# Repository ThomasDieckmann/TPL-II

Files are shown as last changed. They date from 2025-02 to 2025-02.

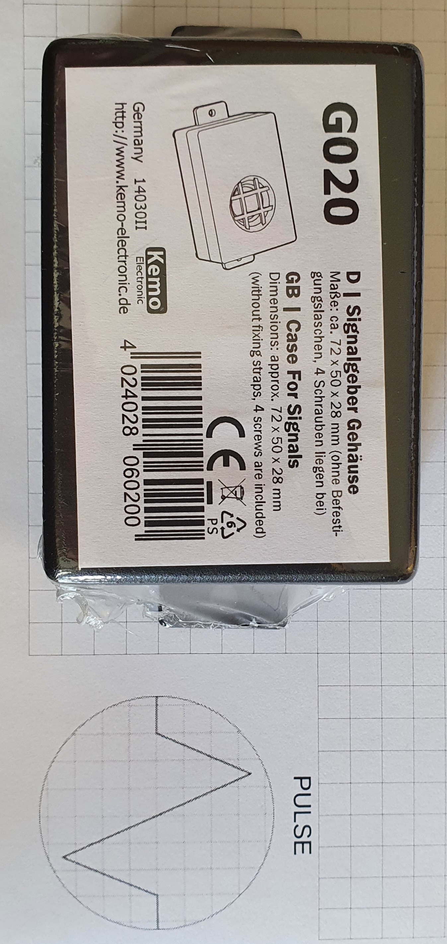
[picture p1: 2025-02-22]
photos/20220920_143856.jpg

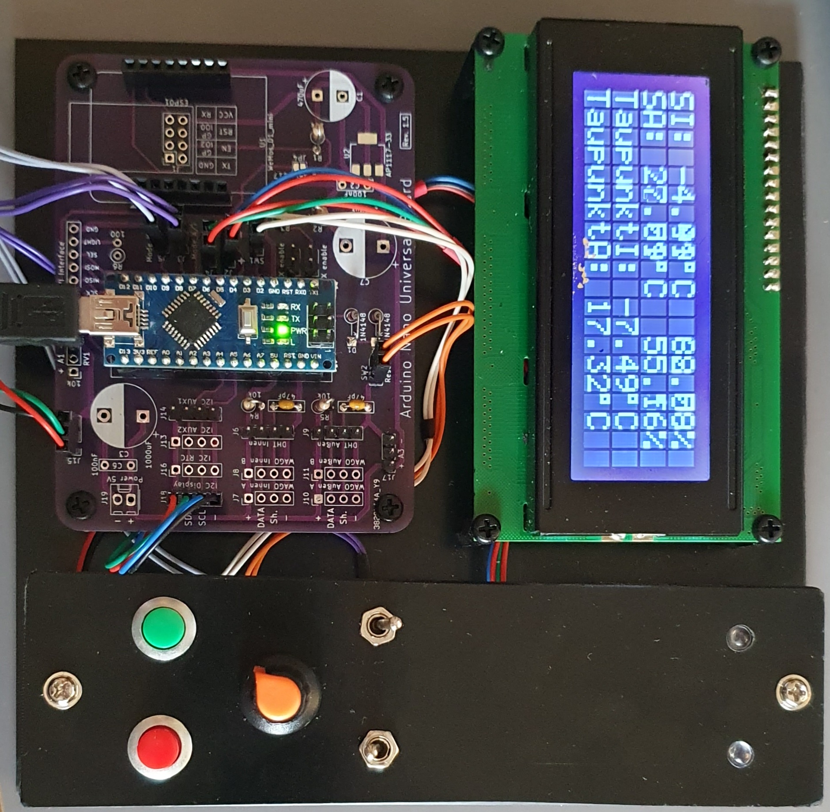
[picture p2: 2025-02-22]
photos/20221109_110422.jpg

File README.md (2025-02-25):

# TPL-II
## Taupunktlüftung II => dewpoint ventilation II
Description in progress....

The original project Taupunktlüftung is created by ct/Heise.

I extended and modified the code for some additional functions and some optional hardware has been added, too.

## purpose, just in case, you don't know...

## Hardware-Overview

the project hardware is based on some separate modules.
1. mainboard
2. power supply
3. relais board
4. I2C display

### the mainboard
the mainboard is developed by myself using KiCAD software. it has sockets for the Arduino nano, which is obligatory and for an ESP01 or Wemos D1. the source code published here is developed with Arduino IDE and has to be uploaded to the Atmega 328P chip with new bootloader. you can add an ESP8266 (wemos D1 mini pro or ESP01) to this system. this additional module is intendet to be programmed with Tasmota firmware. It reads serial data from the Arduino board an can deliver the data to an MQTT server. With serialsend you can use the ESP chip, so send serial data to the Arduino, for example, to initiate a button press.

### power supply

Switching power supply, board creaded with KiCAD. Output is 5V 10W (or more).

### relais board

2 relais baord from a chinese manufacturer. be sure to buy good quality with air gap between the contacts.

### I2C display

LCD background lit text display with 2 x 40 characters HD44780 compatible and I2C interface

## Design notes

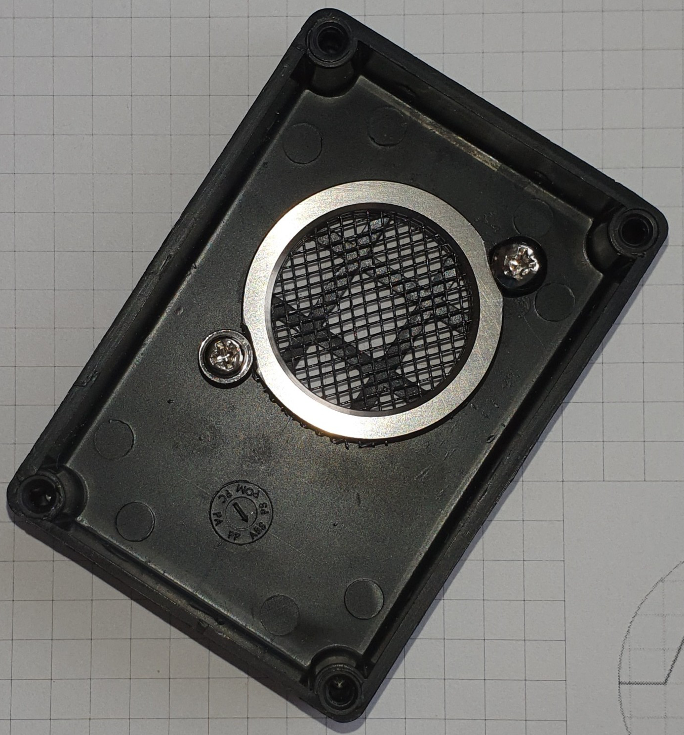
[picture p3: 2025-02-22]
photos/sensor_innen.jpg

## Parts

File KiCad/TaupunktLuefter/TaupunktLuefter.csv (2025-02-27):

Source: | /home/gerbil/KiCad_Projects/TaupunktLuefter/TaupunktLuefter.kicad_sch
Date: | Mi 25 Sep 2024 11:28:30 CEST
Tool: | Eeschema 6.0.11-2627ca5db0~126~ubuntu20.04.1
Generator: | /usr/share/kicad/plugins/bom_csv_grouped_by_value.py
Component Count: | 44
Individual Components:
Item | Qty | Reference(s) | Value | LibPart | Footprint | Datasheet
 |  | A1 | Arduino_Nano_v3.x | MCU_Module:Arduino_Nano_v3.x | Module:Arduino_Nano | http://www.mouser.com/pdfdocs/Gravitech_Arduino_Nano3_0.pdf
 |  | C1 | 470uF | Device:C_Polarized_Small | Capacitor_THT:CP_Radial_D10.0mm_P5.00mm | ~
 |  | C2 | 100nF | Device:C_Small | Capacitor_THT:C_Rect_L7.0mm_W2.0mm_P5.00mm | ~
 |  | C3 | 1000uF | Device:C_Polarized_Small | Capacitor_THT:CP_Radial_D12.5mm_P7.50mm | ~
 |  | C4 | 47pF | Device:C_Small | Capacitor_THT:C_Rect_L7.0mm_W2.0mm_P5.00mm | ~
 |  | C5 | 47pF | Device:C_Small | Capacitor_THT:C_Rect_L7.0mm_W2.0mm_P5.00mm | ~
 |  | C6 | 100nF | Device:C_Small | Capacitor_THT:C_Rect_L7.0mm_W2.0mm_P5.00mm | ~
 |  | C7 | 1000uF | Device:C_Polarized_Small | Capacitor_THT:CP_Radial_D12.5mm_P7.50mm | ~
 |  | D1 | 3V3 | Diode:BZV55B3V3 | Diode_THT:D_A-405_P2.54mm_Vertical_KathodeUp | https://assets.nexperia.com/documents/data-sheet/BZV55_SER.pdf
 |  | D2 | 1N4148 | Device:D_Small_Filled | Diode_THT:D_A-405_P2.54mm_Vertical_KathodeUp | ~
 |  | D3 | 1N4148 | Device:D_Small_Filled | Diode_THT:D_A-405_P2.54mm_Vertical_KathodeUp | ~
 |  | J1 | ESP01 | Connector_Generic:Conn_02x04_Odd_Even | Connector_PinSocket_2.54mm:PinSocket_2x04_P2.54mm_Vertical | ~
 |  | J2 | Rel1 | Connector:Conn_01x03_Male | Connector_PinHeader_2.54mm:PinHeader_1x03_P2.54mm_Vertical | ~
 |  | J3 | Mode_A/T | Connector:Conn_01x02_Male | Connector_PinHeader_2.54mm:PinHeader_1x02_P2.54mm_Vertical | ~
 |  | J4 | Rel2 | Connector:Conn_01x03_Male | Connector_PinHeader_2.54mm:PinHeader_1x03_P2.54mm_Vertical | ~
 |  | J5 | Mode_Kombi | Connector:Conn_01x02_Male | Connector_PinHeader_2.54mm:PinHeader_1x02_P2.54mm_Vertical | ~
 |  | J6 | DHT Innen | Connector:Conn_01x04_Male | Connector_PinHeader_2.54mm:PinHeader_1x04_P2.54mm_Vertical | ~
 |  | J7 | WAGO Innen A | Connector:Conn_01x04_Male | Connector_PinHeader_2.54mm:PinHeader_1x04_P2.54mm_Vertical | ~
 |  | J8 | WAGO Innen B | Connector:Conn_01x04_Male | Connector_PinHeader_2.54mm:PinHeader_1x04_P2.54mm_Vertical | ~
 |  | J9 | DHT Außen | Connector:Conn_01x04_Male | Connector_PinHeader_2.54mm:PinHeader_1x04_P2.54mm_Vertical | ~
 |  | J10 | WAGO Außen A | Connector:Conn_01x04_Male | Connector_PinHeader_2.54mm:PinHeader_1x04_P2.54mm_Vertical | ~
 |  | J11 | WAGO Außen B | Connector:Conn_01x04_Male | Connector_PinHeader_2.54mm:PinHeader_1x04_P2.54mm_Vertical | ~
 |  | J12 | 5V SPI Interface | Connector:Conn_01x08_Male | Connector_PinHeader_2.54mm:PinHeader_1x08_P2.54mm_Vertical | ~
 |  | J13 | I2C AUX2 | Connector:Conn_01x04_Male | Connector_PinHeader_2.54mm:PinHeader_1x04_P2.54mm_Vertical | ~
 |  | J14 | I2C AUX1 | Connector:Conn_01x04_Male | Connector_PinHeader_2.54mm:PinHeader_1x04_P2.54mm_Vertical | ~
 |  | J15 | A2 | Connector:Conn_01x03_Male | Connector_PinHeader_2.54mm:PinHeader_1x03_P2.54mm_Vertical | ~
 |  | J16 | I2C RTC | Connector:Conn_01x04_Male | Connector_PinHeader_2.54mm:PinHeader_1x04_P2.54mm_Vertical | ~
 |  | J17 | A3 | Connector:Conn_01x03_Male | Connector_PinHeader_2.54mm:PinHeader_1x03_P2.54mm_Vertical | ~
 |  | J18 | I2C Display | Connector:Conn_01x04_Male | Connector_PinHeader_2.54mm:PinHeader_1x04_P2.54mm_Vertical | ~
 |  | J19 | Power 5V | Connector:Conn_01x02_Male | Connector_Molex:Molex_KK-254_AE-6410-02A_1x02_P2.54mm_Vertical | ~
 |  | JP1 | RX enable | Jumper:Jumper_2_Bridged | Connector_PinHeader_2.54mm:PinHeader_1x02_P2.54mm_Vertical | ~
 |  | JP2 | TX enable | Jumper:Jumper_2_Bridged | Connector_PinHeader_2.54mm:PinHeader_1x02_P2.54mm_Vertical | ~
 |  | JP3 | 3V3 Sel Nano | Jumper:SolderJumper_2_Open | Jumper:SolderJumper-2_P1.3mm_Open_Pad1.0x1.5mm | ~
 |  | JP4 | 3V3 Sel 1117 | Jumper:SolderJumper_2_Open | Jumper:SolderJumper-2_P1.3mm_Open_Pad1.0x1.5mm | ~
 |  | R1 | 10k | Device:R | Resistor_THT:R_Axial_DIN0207_L6.3mm_D2.5mm_P2.54mm_Vertical | ~
 |  | R2 | 1k | Device:R | Resistor_THT:R_Axial_DIN0207_L6.3mm_D2.5mm_P2.54mm_Vertical | ~
 |  | R3 | 10k | Device:R | Resistor_THT:R_Axial_DIN0207_L6.3mm_D2.5mm_P2.54mm_Vertical | ~
 |  | R4 | 10k | Device:R | Resistor_THT:R_Axial_DIN0207_L6.3mm_D2.5mm_P2.54mm_Vertical | ~
 |  | R5 | 100 | Device:R | Resistor_THT:R_Axial_DIN0207_L6.3mm_D2.5mm_P2.54mm_Vertical | ~
 |  | RV1 | 10k | Device:R_Potentiometer | Connector_PinHeader_2.54mm:PinHeader_1x03_P2.54mm_Vertical | ~
 |  | SW1 | Timer | Switch:SW_Push | Connector_PinHeader_2.54mm:PinHeader_1x02_P2.54mm_Vertical | ~
 |  | SW2 | Reset | Switch:SW_Push | Connector_PinHeader_2.54mm:PinHeader_1x02_P2.54mm_Vertical | ~
 |  | U1 | WeMos_D1_mini | MCU_Module:WeMos_D1_mini | Module:WEMOS_D1_mini_light | https://wiki.wemos.cc/products:d1:d1_mini#documentation
 |  | U2 | AP1117-33 | Regulator_Linear:AP1117-33 | Package_TO_SOT_SMD:SOT-223-3_TabPin2 | http://www.diodes.com/datasheets/AP1117.pdf
Collated Components:
Item | Qty | Reference(s) | Value | LibPart | Footprint | Datasheet
1 | 1 | A1 | Arduino_Nano_v3.x | MCU_Module:Arduino_Nano_v3.x | Module:Arduino_Nano | http://www.mouser.com/pdfdocs/Gravitech_Arduino_Nano3_0.pdf
2 | 1 | C1 | 470uF | Device:C_Polarized_Small | Capacitor_THT:CP_Radial_D10.0mm_P5.00mm | ~
3 | 2 | C2, C6 | 100nF | Device:C_Small | Capacitor_THT:C_Rect_L7.0mm_W2.0mm_P5.00mm | ~
4 | 2 | C3, C7 | 1000uF | Device:C_Polarized_Small | Capacitor_THT:CP_Radial_D12.5mm_P7.50mm | ~
5 | 2 | C4, C5 | 47pF | Device:C_Small | Capacitor_THT:C_Rect_L7.0mm_W2.0mm_P5.00mm | ~
6 | 1 | D1 | 3V3 | Diode:BZV55B3V3 | Diode_THT:D_A-405_P2.54mm_Vertical_KathodeUp | https://assets.nexperia.com/documents/data-sheet/BZV55_SER.pdf
7 | 2 | D2, D3 | 1N4148 | Device:D_Small_Filled | Diode_THT:D_A-405_P2.54mm_Vertical_KathodeUp | ~
8 | 1 | J1 | ESP01 | Connector_Generic:Conn_02x04_Odd_Even | Connector_PinSocket_2.54mm:PinSocket_2x04_P2.54mm_Vertical | ~
9 | 1 | J2 | Rel1 | Connector:Conn_01x03_Male | Connector_PinHeader_2.54mm:PinHeader_1x03_P2.54mm_Vertical | ~
10 | 1 | J3 | Mode_A/T | Connector:Conn_01x02_Male | Connector_PinHeader_2.54mm:PinHeader_1x02_P2.54mm_Vertical | ~
11 | 1 | J4 | Rel2 | Connector:Conn_01x03_Male | Connector_PinHeader_2.54mm:PinHeader_1x03_P2.54mm_Vertical | ~
12 | 1 | J5 | Mode_Kombi | Connector:Conn_01x02_Male | Connector_PinHeader_2.54mm:PinHeader_1x02_P2.54mm_Vertical | ~
13 | 1 | J6 | DHT Innen | Connector:Conn_01x04_Male | Connector_PinHeader_2.54mm:PinHeader_1x04_P2.54mm_Vertical | ~
14 | 1 | J7 | WAGO Innen A | Connector:Conn_01x04_Male | Connector_PinHeader_2.54mm:PinHeader_1x04_P2.54mm_Vertical | ~
15 | 1 | J8 | WAGO Innen B | Connector:Conn_01x04_Male | Connector_PinHeader_2.54mm:PinHeader_1x04_P2.54mm_Vertical | ~
16 | 1 | J9 | DHT Außen | Connector:Conn_01x04_Male | Connector_PinHeader_2.54mm:PinHeader_1x04_P2.54mm_Vertical | ~
17 | 1 | J10 | WAGO Außen A | Connector:Conn_01x04_Male | Connector_PinHeader_2.54mm:PinHeader_1x04_P2.54mm_Vertical | ~
18 | 1 | J11 | WAGO Außen B | Connector:Conn_01x04_Male | Connector_PinHeader_2.54mm:PinHeader_1x04_P2.54mm_Vertical | ~
19 | 1 | J12 | 5V SPI Interface | Connector:Conn_01x08_Male | Connector_PinHeader_2.54mm:PinHeader_1x08_P2.54mm_Vertical | ~
20 | 1 | J13 | I2C AUX2 | Connector:Conn_01x04_Male | Connector_PinHeader_2.54mm:PinHeader_1x04_P2.54mm_Vertical | ~
21 | 1 | J14 | I2C AUX1 | Connector:Conn_01x04_Male | Connector_PinHeader_2.54mm:PinHeader_1x04_P2.54mm_Vertical | ~
22 | 1 | J15 | A2 | Connector:Conn_01x03_Male | Connector_PinHeader_2.54mm:PinHeader_1x03_P2.54mm_Vertical | ~
23 | 1 | J16 | I2C RTC | Connector:Conn_01x04_Male | Connector_PinHeader_2.54mm:PinHeader_1x04_P2.54mm_Vertical | ~
24 | 1 | J17 | A3 | Connector:Conn_01x03_Male | Connector_PinHeader_2.54mm:PinHeader_1x03_P2.54mm_Vertical | ~
25 | 1 | J18 | I2C Display | Connector:Conn_01x04_Male | Connector_PinHeader_2.54mm:PinHeader_1x04_P2.54mm_Vertical | ~
26 | 1 | J19 | Power 5V | Connector:Conn_01x02_Male | Connector_Molex:Molex_KK-254_AE-6410-02A_1x02_P2.54mm_Vertical | ~
27 | 1 | JP1 | RX enable | Jumper:Jumper_2_Bridged | Connector_PinHeader_2.54mm:PinHeader_1x02_P2.54mm_Vertical | ~
28 | 1 | JP2 | TX enable | Jumper:Jumper_2_Bridged | Connector_PinHeader_2.54mm:PinHeader_1x02_P2.54mm_Vertical | ~
29 | 1 | JP3 | 3V3 Sel Nano | Jumper:SolderJumper_2_Open | Jumper:SolderJumper-2_P1.3mm_Open_Pad1.0x1.5mm | ~
30 | 1 | JP4 | 3V3 Sel 1117 | Jumper:SolderJumper_2_Open | Jumper:SolderJumper-2_P1.3mm_Open_Pad1.0x1.5mm | ~
31 | 3 | R1, R3, R4 | 10k | Device:R | Resistor_THT:R_Axial_DIN0207_L6.3mm_D2.5mm_P2.54mm_Vertical | ~
32 | 1 | R2 | 1k | Device:R | Resistor_THT:R_Axial_DIN0207_L6.3mm_D2.5mm_P2.54mm_Vertical | ~
33 | 1 | R5 | 100 | Device:R | Resistor_THT:R_Axial_DIN0207_L6.3mm_D2.5mm_P2.54mm_Vertical | ~
34 | 1 | RV1 | 10k | Device:R_Potentiometer | Connector_PinHeader_2.54mm:PinHeader_1x03_P2.54mm_Vertical | ~
35 | 1 | SW1 | Timer | Switch:SW_Push | Connector_PinHeader_2.54mm:PinHeader_1x02_P2.54mm_Vertical | ~
36 | 1 | SW2 | Reset | Switch:SW_Push | Connector_PinHeader_2.54mm:PinHeader_1x02_P2.54mm_Vertical | ~
37 | 1 | U1 | WeMos_D1_mini | MCU_Module:WeMos_D1_mini | Module:WEMOS_D1_mini_light | https://wiki.wemos.cc/products:d1:d1_mini#documentation
38 | 1 | U2 | AP1117-33 | Regulator_Linear:AP1117-33 | Package_TO_SOT_SMD:SOT-223-3_TabPin2 | http://www.diodes.com/datasheets/AP1117.pdf

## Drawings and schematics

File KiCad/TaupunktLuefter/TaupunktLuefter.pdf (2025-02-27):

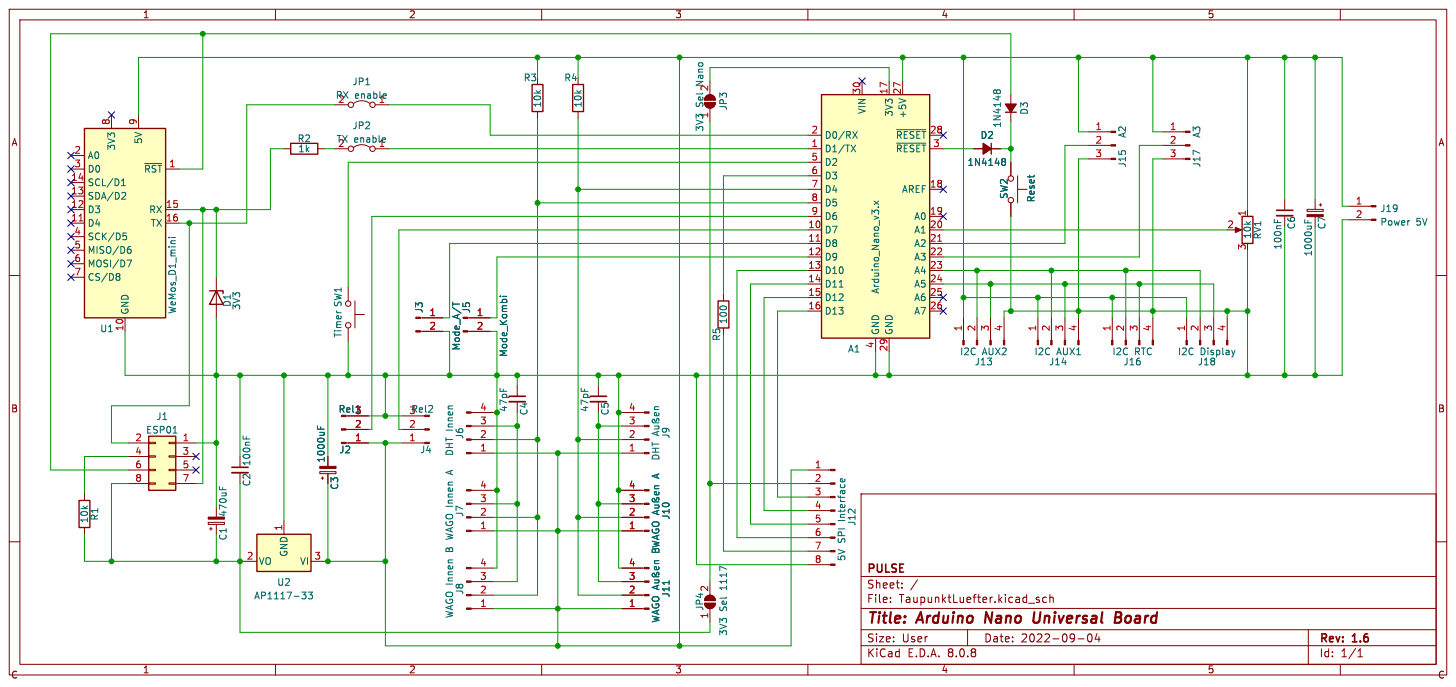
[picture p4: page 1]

Sheet: /
File: TaupunktLuefter.kicad_sch
Title: Arduino Nano Universal Board

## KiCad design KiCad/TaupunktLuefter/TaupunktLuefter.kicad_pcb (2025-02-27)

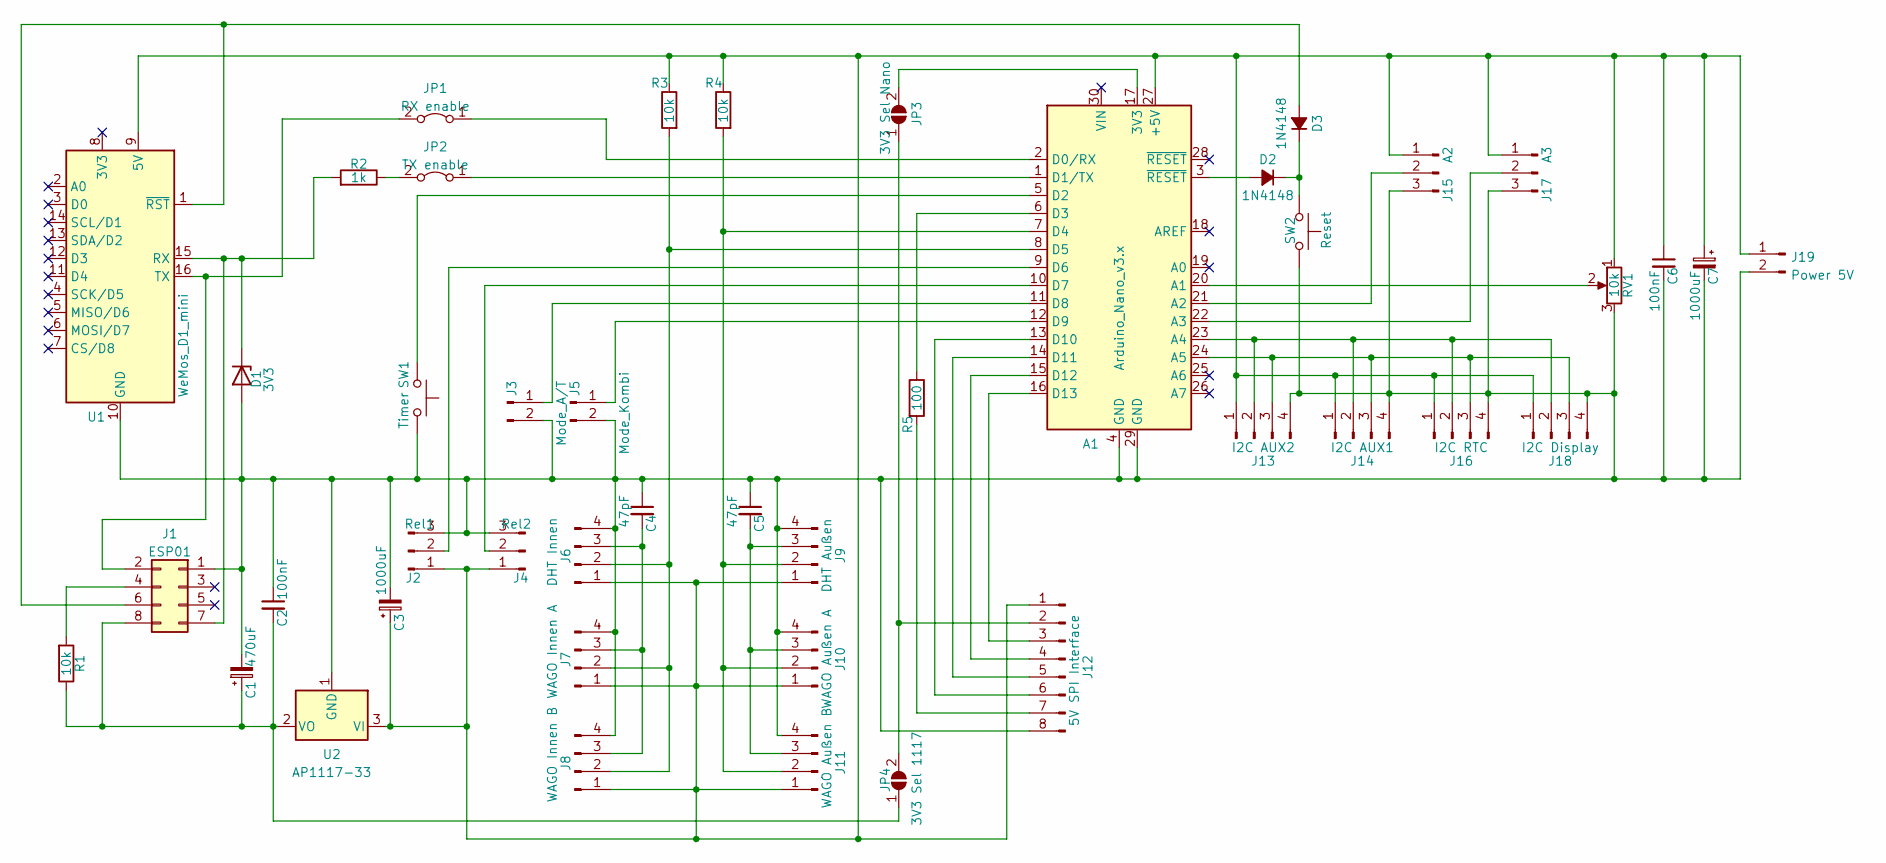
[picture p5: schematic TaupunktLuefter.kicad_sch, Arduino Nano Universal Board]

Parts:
A1: Arduino_Nano_v3.x; Arduino_Nano
C1: 470uF; CP_Radial_D10.0mm_P5.00mm
C2, C6: 100nF; C_Rect_L7.0mm_W2.0mm_P5.00mm
C3, C7: 1000uF; CP_Radial_D12.5mm_P7.50mm
C4, C5: 47pF; C_Rect_L7.0mm_W2.0mm_P5.00mm
D1: 3V3; D_A-405_P2.54mm_Vertical_KathodeUp
D2, D3: 1N4148; D_A-405_P2.54mm_Vertical_KathodeUp
J1: ESP01; PinSocket_2x04_P2.54mm_Vertical
J2: Rel1; PinHeader_1x03_P2.54mm_Vertical
J3: Mode_A/T; PinHeader_1x02_P2.54mm_Vertical
J4: Rel2; PinHeader_1x03_P2.54mm_Vertical
J5: Mode_Kombi; PinHeader_1x02_P2.54mm_Vertical
J6: DHT Innen; PinHeader_1x04_P2.54mm_Vertical
J7: WAGO Innen A; PinHeader_1x04_P2.54mm_Vertical
J8: WAGO Innen B; PinHeader_1x04_P2.54mm_Vertical
J9: DHT Außen; PinHeader_1x04_P2.54mm_Vertical
J10: WAGO Außen A; PinHeader_1x04_P2.54mm_Vertical
J11: WAGO Außen B; PinHeader_1x04_P2.54mm_Vertical
J12: 5V SPI Interface; PinHeader_1x08_P2.54mm_Vertical
J13: I2C AUX2; PinHeader_1x04_P2.54mm_Vertical
J14: I2C AUX1; PinHeader_1x04_P2.54mm_Vertical
J15: A2; PinHeader_1x03_P2.54mm_Vertical
J16: I2C RTC; PinHeader_1x04_P2.54mm_Vertical
J17: A3; PinHeader_1x03_P2.54mm_Vertical
J18: I2C Display; PinHeader_1x04_P2.54mm_Vertical
J19: Power 5V; Molex_KK-254_AE-6410-02A_1x02_P2.54mm_Vertical
JP1: RX enable; PinHeader_1x02_P2.54mm_Vertical
JP2: TX enable; PinHeader_1x02_P2.54mm_Vertical
JP3: 3V3 Sel Nano; SolderJumper-2_P1.3mm_Open_Pad1.0x1.5mm
JP4: 3V3 Sel 1117; SolderJumper-2_P1.3mm_Open_Pad1.0x1.5mm
R1, R3, R4: 10k; R_Axial_DIN0207_L6.3mm_D2.5mm_P2.54mm_Vertical
R2: 1k; R_Axial_DIN0207_L6.3mm_D2.5mm_P2.54mm_Vertical
R5: 100; R_Axial_DIN0207_L6.3mm_D2.5mm_P2.54mm_Vertical
RV1: 10k; PinHeader_1x03_P2.54mm_Vertical
SW1: Timer; PinHeader_1x02_P2.54mm_Vertical
SW2: Reset; PinHeader_1x02_P2.54mm_Vertical
U1: WeMos_D1_mini; WEMOS_D1_mini_light
U2: AP1117-33; SOT-223-3_TabPin2

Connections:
unnamed: A1.1 (D1/TX), JP2.1 (A)
unnamed: A1.2 (D0/RX), JP1.1 (A)
unnamed: A1.3 (~RESET), D2.2 (A)
unnamed: A1.5 (D2), SW1.1
unnamed: A1.6 (D3), R5.1
unnamed: A1.7 (D4), J9.2, J10.2, J11.2, R4.2
unnamed: A1.8 (D5), J6.2, J7.2, J8.2, R3.2
unnamed: A1.9 (D6), J2.2
unnamed: A1.10 (D7), J4.2
unnamed: A1.11 (D8), J3.1
unnamed: A1.12 (D9), J5.1
unnamed: A1.13 (D10), J12.6
unnamed: A1.14 (D11), J12.5
unnamed: A1.15 (D12), J12.4
unnamed: A1.16 (D13), J12.3
unnamed: A1.17 (3V3), JP3.2 (B)
unnamed: A1.20 (A1), RV1.2
unnamed: A1.21 (A2), J15.2
unnamed: A1.22 (A3), J17.2
unnamed: A1.23 (A4), J13.2, J14.2, J16.2, J18.2
unnamed: A1.24 (A5), J13.3, J14.3, J16.3, J18.3
unnamed: A1.27 (+5V), C3.1, C6.1, C7.1, J2.1, J4.1, J6.1, J7.1, J8.1, J9.1, J10.1, J11.1, J12.1, J13.1, J14.1, J15.1, J16.1, J17.1, J18.1, J19.1, R3.1, R4.1, RV1.1, U1.9 (5V), U2.3 (VI)
unnamed: A1.4 (GND), A1.29 (GND), C1.2, C2.1, C3.2, C4.1, C5.1, C6.2, C7.2, D1.2 (A), J1.1, J2.3, J3.2, J4.3, J5.2, J6.4, J7.4, J8.4, J9.4, J10.4, J11.4, J12.8, J13.4, J14.4, J15.3, J16.4, J17.3, J18.4, J19.2, RV1.3, SW1.2, SW2.2, U1.10 (GND), U2.1 (GND)
unnamed: C1.1, C2.2, J1.8, JP4.1 (A), R1.1, U2.2 (VO)
unnamed: C4.2, J6.3, J7.3, J8.3
unnamed: C5.2, J9.3, J10.3, J11.3
unnamed: D2.1 (K), D3.1 (K), SW2.1
unnamed: D3.2 (A), J1.6, U1.1 (~RST)
unnamed: J1.2, JP1.2 (B), U1.16 (TX)
unnamed: J1.4, R1.2
unnamed: D1.1 (K), J1.7, R2.2, U1.15 (RX)
unnamed: J12.2, JP3.1 (A), JP4.2 (B)
unnamed: J12.7, R5.2
unnamed: JP2.2 (B), R2.1

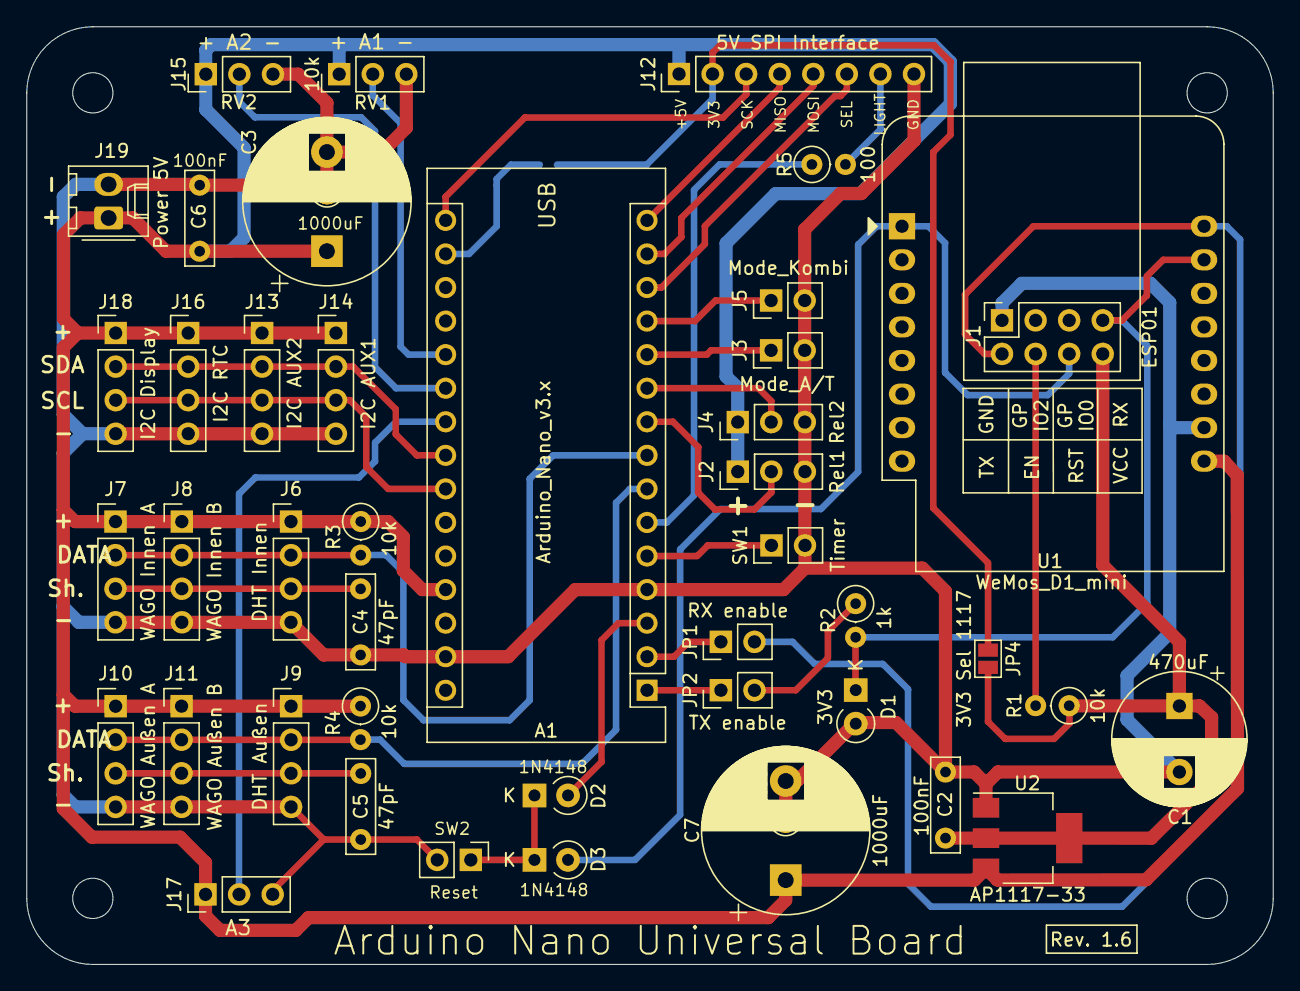
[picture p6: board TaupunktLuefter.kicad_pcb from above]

Board: 2 copper layers, 94.3 x 71.0 mm, 44 parts (1 on the bottom side), 34 nets.

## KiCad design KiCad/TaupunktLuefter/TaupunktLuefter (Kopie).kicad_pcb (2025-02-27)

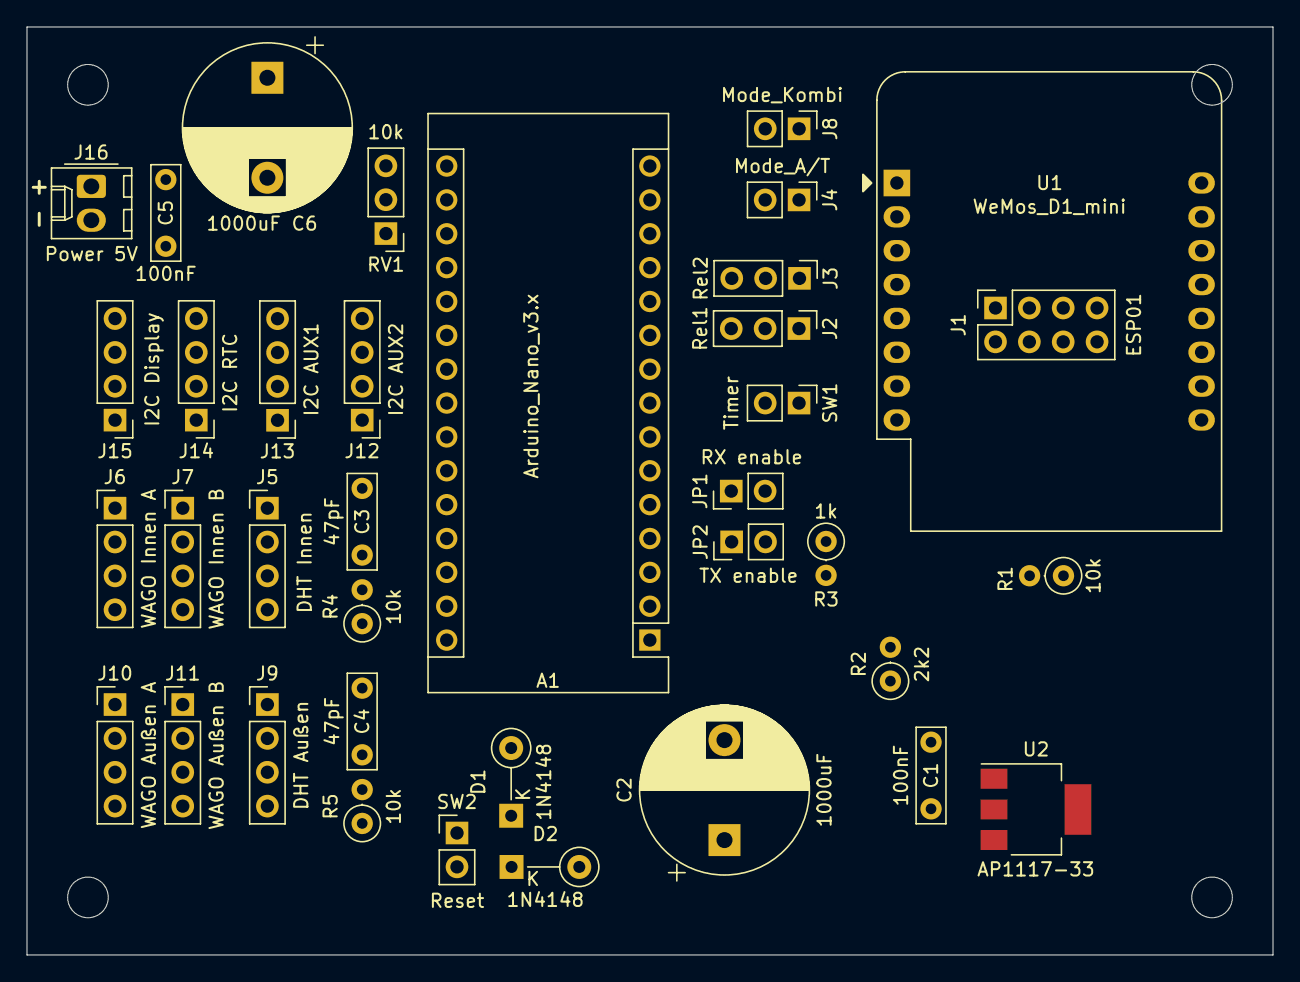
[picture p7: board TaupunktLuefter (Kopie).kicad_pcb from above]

Board: 2 copper layers, 93.5 x 69.6 mm, 37 parts (0 on the bottom side), 25 nets, no tracks yet.

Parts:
A1: Arduino_Nano_v3.x; Arduino_Nano
C1, C5: 100nF; C_Rect_L7.0mm_W2.0mm_P5.00mm
C2, C6: 1000uF; CP_Radial_D12.5mm_P7.50mm
C3, C4: 47pF; C_Rect_L7.0mm_W2.0mm_P5.00mm
D1, D2: 1N4148; D_A-405_P5.08mm_Vertical_KathodeUp
J1: ESP01; PinSocket_2x04_P2.54mm_Vertical
J2: Rel1; PinHeader_1x03_P2.54mm_Vertical
J3: Rel2; PinHeader_1x03_P2.54mm_Vertical
J4: Mode_A/T; PinHeader_1x02_P2.54mm_Vertical
J5: DHT Innen; PinHeader_1x04_P2.54mm_Vertical
J6: WAGO Innen A; PinHeader_1x04_P2.54mm_Vertical
J7: WAGO Innen B; PinHeader_1x04_P2.54mm_Vertical
J8: Mode_Kombi; PinHeader_1x02_P2.54mm_Vertical
J9: DHT Außen; PinHeader_1x04_P2.54mm_Vertical
J10: WAGO Außen A; PinHeader_1x04_P2.54mm_Vertical
J11: WAGO Außen B; PinHeader_1x04_P2.54mm_Vertical
J12: I2C AUX2; PinHeader_1x04_P2.54mm_Vertical
J13: I2C AUX1; PinHeader_1x04_P2.54mm_Vertical
J14: I2C RTC; PinHeader_1x04_P2.54mm_Vertical
J15: I2C Display; PinHeader_1x04_P2.54mm_Vertical
J16: Power 5V; Molex_KK-254_AE-6410-02A_1x02_P2.54mm_Vertical
JP1: RX enable; PinHeader_1x02_P2.54mm_Vertical
JP2: TX enable; PinHeader_1x02_P2.54mm_Vertical
R1, R4, R5: 10k; R_Axial_DIN0207_L6.3mm_D2.5mm_P2.54mm_Vertical
R2: 2k2; R_Axial_DIN0207_L6.3mm_D2.5mm_P2.54mm_Vertical
R3: 1k; R_Axial_DIN0207_L6.3mm_D2.5mm_P2.54mm_Vertical
RV1: 10k; PinHeader_1x03_P2.54mm_Vertical
SW1: Timer; PinHeader_1x02_P2.54mm_Vertical
SW2: Reset; PinHeader_1x02_P2.54mm_Vertical
U1: WeMos_D1_mini; WEMOS_D1_mini_light
U2: AP1117-33; SOT-223-3_TabPin2

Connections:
unnamed: A1.1 (D1/TX), JP2.1 (A)
unnamed: A1.2 (D0/RX), JP1.1 (A)
unnamed: A1.5 (D2), SW1.2
unnamed: A1.7 (D4), J9.3, J10.3, J11.3, R5.2
unnamed: A1.8 (D5), J5.3, J6.3, J7.3, R4.2
unnamed: A1.9 (D6), J2.2
unnamed: A1.10 (D7), J3.2
unnamed: A1.11 (D8), J4.2
unnamed: A1.20 (A1), RV1.2
unnamed: A1.23 (A4), J12.3, J13.3, J14.3, J15.3
unnamed: A1.24 (A5), J12.2, J13.2, J14.2, J15.2
unnamed: A1.27 (+5V), C5.1, C6.1, J5.4, J6.4, J7.4, J9.4, J10.4, J11.4, J12.4, J13.4, J14.4, J15.4, J16.1, R4.1, R5.1, RV1.1, U1.9 (5V)
unnamed: A1.28 (~RESET), D1.2 (A)
unnamed: C1.2, J1.8, R1.1, U2.2 (VO)
unnamed: C2.1, J2.3, J3.3, U2.3 (VI)
unnamed: C3.2, J5.2, J6.2, J7.2
unnamed: C4.2, J9.2, J10.2, J11.2
unnamed: D1.1 (K), D2.1 (K), SW2.2
unnamed: D2.2 (A), J1.6, U1.1 (~RST)
unnamed: A1.4 (GND), A1.29 (GND), C1.1, C2.2, C3.1, C4.1, C5.2, C6.2, J1.1, J2.1, J3.1, J4.1, J5.1, J6.1, J7.1, J8.1, J9.1, J10.1, J11.1, J12.1, J13.1, J14.1, J15.1, J16.2, R2.1, RV1.3, SW1.1, SW2.1, U1.10 (GND), U2.1 (GND)
unnamed: J1.2, JP1.2 (B), U1.16 (TX)
unnamed: J1.4, R1.2
unnamed: A1.12 (D9), J8.2
unnamed: JP2.2 (B), R3.1
unnamed: J1.7, R2.2, R3.2, U1.15 (RX)

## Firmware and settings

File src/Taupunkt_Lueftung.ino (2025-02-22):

/* 

Original bei Heise
Upgrade by Thomas Dieckmann ;-)


Entwicklungs-Plattform: Arduino IDE 1.8.19 / Linux

Pinbelegung Arduino Nano:
=========================

D0   RX                   D11  opt. MOSI
D1   TX                   D12  opt. MISO
D2   Timer_Knopf          D13  opt. SCK/LED f. Serial ACK
D3                        A0   Randomizer (frei)
D4   DHT außen            A1   
D5   DHT innen            A2   Poti
D6   Relais1              A3
D7   Relais2              A4   I2C SDA
D8   MODE: Timer/Auto     A5   I2C SCL
D9   MODE: Timer&Sensor   A6
D10  opt. CS              A7



HELP: https://jsonformatter.org/#

"Innen":{"Temperature":7.86,"Humidity":40.86,"DewPoint":-4.60},"Aussen":{"Temperature":15.86,"Humidity":45.86,"DewPoint":4.23},"Timer":{"Preset":300,"Remain":0},"Actuators":{"Relay1":"OFF","Relay2":"OFF"},"Mode":"Combi2","TempUnit":"C","TimeUnit":"seconds","Version":"1.5.7"}

==>
=== test:     
*/

#define PRG_VERSION               "2.0.5"
#define EEPROM_ID_WERT            1     // sozusagen eine Sub-Version um zu prüfen, ob Settings aus dem EEPROM gelesen werden sollen
#define EEPROM_BANK               0     // Speicher-Seite, damit die Daten woanders liegen können um den EEPORM-Speicher zu schonen
#define EEPROM_BANKGROESSE        16    // definiert die Größe der Speicherbank (derzeit 16)

// l10n stuff
#define DE 1
#define EN 2
#define LANGUAGE DE

/* Commands:
 *  B   press button
 *  0   timer = zero
 *  J   send JSON
 *  P   ping
 *  RR  reset 328P chip
 */
/*
   TODO/Changelog
   ==============

   Todo:
   - optimizing Display outputs (obvious after starting, with lange page refresh interval)
   - password-option, block setup (Pfeil zurück Seite 2 Zeile 1 Symbol 15)
   - Bugs: A/H command don't work properly

   
   V2.0.5 v. 17.01.2024:
   ---------------------
   - remove password routine, i'll decide later, if it'll be needed, when it's ready...

   V2.0.4 v. 17.01.2024:
   ---------------------
   - Bugs: Offset/settings for inner temp / outer temp

   V2.0.3 v. 17.01.2024:
   ---------------------
   - some changes for Config/commands

   V2.0.2 v. 16.01.2024:
   ---------------------
   - accept commands and use switch-structure... BOJPR
   
   V2.0.1 v. 16.01.2024:
   ---------------------
   - accept O via Serial as reset Timer to zero
   - accept R via Serial as Reset, has to be repeated

   V2.0.0 v. 16.01.2024:
   ---------------------
   - accept B via Serial as BUTTON
   
   V1.5.8 v. 13.01.2024:
   ---------------------
   - interprete any serial input from 8266 as Trigger

   V1.5.7 v. 12.01.2024:
   ---------------------
   - simplified JSON output

   V1.5.6 v. 03.10.2023:
   ---------------------
   - bug: temperature calibration

   V1.5.5 v. 01.10.2023:
   ---------------------
   - möglicher Fehler bei Temperatur-Kalibrierung => zunächst bei Dummy-Sensor-Werten
     Fix-Temperatur und dann Suche nach Codestellen, wo es haken könnte
     => vermutlich durch Groß/Kleinschreibung gelöst
   
   V1.5.4 v. 25.11.2022:
   ---------------------
   - l10n: DE & EN for german and english

   V1.5.3 v. 24.11.2022:
   ---------------------
   - EEPROM-BANK Größe verwenden, damit später vergrößert und das Passwort
     abgespeichert werden kann

   V1.5.2 v. 23.11.2022:
   ---------------------
   - Zusammenfassung von Textausgaben mit Sonderzeichen (oktal) spart Speicherplatz
   - Funktion für Grad-Celsius-Anzeige besser genutzt, spart auch Speicher
   - Ersatz ß gegen ss in Übergabestring für Tasmota Serial2MQTT-Bridge,
     JSON wird nun sauber erkannt
   - einfache serielle Debugging Ausgaben nur noch, wenn kein JSON ausgegeben wird
   - Vorbereitung größere EEPROM-BANK für Passwort etc.

   V1.5.1 v. 16.11.2022:
   ---------------------
   - Auslagerung ja/nein-Funktion, die wird häufiger benötigt

   V1.5.0 v. 11.11.2022:
   ---------------------
   - Einbau Speicherroutine unter Verwendung verschiedener Speicherblöcke um EEPROM zu schonen

   V1.4.9 v. 11.11.2022:
   ---------------------
   - Ausgabe sämtlicher Einstellungsmöglichkeiten => Menue
   - Speichern erst einmal deaktiviert, Speicherroutine muss noch codiert werden

   V1.4.8 v. 10.11.2022:
   ---------------------
   - Setup-Routine für Hysterese, Differenz, Sensor-Korrektur-Werte
     derzeit realisiert: Schalt-Differenz und Hysterese
                         Speichern im EEPROM

   V1.4.7 v. 09.11.2022:
   ---------------------
   - Bugfix: Feuchte-Update bei jedem Durchlauf auf Seite 1, alt-Wert wurde nicht gesetzt

   V1.4.6 v. 09.11.2022:
   ---------------------
   - Ausgabe Sensoren-Check von 1+2 auf Innen/Außen geändert
   - 4. Betriebsart = Kombi-2, Also erst Timer, dann Auto
   - Bei Änderung der Betriebsart wird Seite2 angezeigt
   - Bugfix: nach Wechsel auf Seite 1 wird bsp. 1° bzw. 1% zu viel angezeigt
     (Vorsicht bei ++ Verwendung! a = b++; ist nicht immer gewollt!)
   
   V1.4.5 v. 27.08.2022:
   ---------------------
   - Korrektur der Sekundenanzeige (cast: long bei JSON-String)   ok, beide Teile des Produktes gecastet... dann passt's.
   
   V1.4.4 v. 26.08.2022:
   ---------------------
   - optionale serielle Ausgabe als JSON-String per #define       ok, per define JSON_OUTPUT

   V1.4.3 v. 26.08.2022:
   ---------------------
   - Dummy-Sensoren einzeln per #DEFINE
   
   V1.4.2 v. 25.08.2022:
   ---------------------
   - Komplizierten Wechsel-Murks der Animation wegmachen           ok, umgestellt auf Zähler und index
   - Eigenen Timer dafür einbauen, wie beim Seitenwechsel          ok
   - Zugriff per char(symbol_zaehler) (0 bis MAXSYMBOLS)           ok, siehe oben
     dann braucht es rest_laufzeit_fuenftel oder wasauchimmer
     nicht mehr.
   - elegantere Lösung mit den #ifdefs finden vielleicht kann      ok, #if a == b...
     das nach dem #ifdef mit einfachen ifs machen?
   - ein paar Animationen hinzufügen                               ok
*/

// Dieser Code benötigt zwingend die folgenden Libraries:
#include "DHT.h"
#include <Wire.h> 
#include <LiquidCrystal_I2C.h>
#include <avr/wdt.h>
#include <EEPROM.h>


#if LANGUAGE == DE
   #include "l10n/constants_de.h"
#elif LANGUAGE == EN
   #include "l10n/constants_en.h"
#endif




// #define DISPLAYTEST                          // Testen des LCD Character-Set
// #define DEBUG                                // eventuell bleibt etwas Test-Code übrig
#define WRITE_EEPROM                            // Aktiviere EEPROM Schreib-Routine
//#define DUMMYSENSOR_I                           // wenn man keine Sensoren hat, hilft der Zufall
//#define DUMMYSENSOR_A                           // wenn man keine Sensoren hat, hilft der Zufall
#define SYMBOLSET                  3            // verschiedene Symbolsets möglich (für Animation)
// ***************  Arduino-Pin-Definitionen (siehe oben)  **************
#define TIMER_KNOPF_PIN            2            // Eingang (interner) Pull-Up für Auslösung Timer
#define DHTPIN_AUSSEN              4            // Datenleitung für den DHT-Sensor 2 (außen)
#define DHTPIN_INNEN               5            // Datenleitung für den DHT-Sensor 1 (innen)
#define RELAIS1_PIN                6            // Anschluss des Lüfter-Relais #1
#define RELAIS2_PIN                7            // Anschluss des Lüfter-Relais #2
#define TIMER_AUTO_PIN             8            // Schalter Timer/Auto
#define KOMBI_PIN                  9            // Timer und Sensor kombiniert (interner Pullup)
#define POTI_PIN                   A2           // Pin für das Timer-Poti die 10bit werden umgerechnet auf 1-25
#define ACK_PIN                    13           // Quittierungs-Pin
//  *****************  für bessere Wartbarkeit des Codes  ***************
#define FORCE                      true         // erzwingen der Ausgabe wg. Wechsel der Seite
#define RELAIS_EIN                 LOW          // Das Relais wird geschaltet, wenn der Eingang auf TTL LOW liegt
#define RELAIS_AUS                 HIGH
#define MODE_TIMER                 LOW          // wenn LOW, dann ist der Lüfter aus oder vom Timer gesteuert
#define MODE_KOMBI                 LOW          // wenn LOW, dann kombiniere Timer & Sensor-Betrieb
#define DHTTYPE_INNEN              DHT22        // DHT 22 innen
#define DHTTYPE_AUSSEN             DHT22        // DHT 22 außen
#define SENSOR_INTERVALL           3            // in Sekunden, Pausen zwischen den Auslesezyklen für die Sensoren
#define SEITEN_INTERVALL           7            // in Sekunden, Wartezeit auf Seitenwechsel
// *************  Korrekturwerte der einzelnen Sensorwerte  *************
#define KORREKTUR_TEMP_INNEN      -1            // Korrekturwert Innensensor Temperatur
#define KORREKTUR_TEMP_AUSSEN     -1            // Korrekturwert Außensensor Temperatur
#define KORREKTUR_FEUCHTE_INNEN    0            // Korrekturwert Innensensor Luftfeuchtigkeit
#define KORREKTUR_FEUCHTE_AUSSEN   0            // Korrekturwert Außensensor Luftfeuchtigkeit
// *******************  weitere wichtige Konstanten  ********************
#define SCHALT_MIN                 2.5          // minimaler Taupunktunterschied, bei dem das Relais schaltet
#define HYSTERESE                  1.0          // Abstand von Ein- und Ausschaltpunkt
#define TEMP_INNEN_MIN            10.0          // Minimale Innentemperatur, bei der die Lüftung aktiviert wird
#define TEMP_AUSSEN_MIN          -10.0          // Minimale Außentemperatur, bei der die Lüftung aktiviert wird
#define MAX_MILLIS                 4294967295   // millis() liefert den Datentyp unsigned long, also 32 bit
#define MAX_EINSTELLWERTE          9            // Anzahl der Werte, die angesehen und verändert werden können
// **************************  Betriebsarten  ****************************
#define BETRIEBSART_AUTO           0
#define BETRIEBSART_TIMER          1
#define BETRIEBSART_KOMBI_1        2
#define BETRIEBSART_KOMBI_2        3
// ******************  Optionen für Eingaberoutine  **********************                    
#define OPTION_GRAD                0
#define OPTION_FEUCHTE             1
#define OPTION_SEKUNDEN            2
#define MAX_PASSWORT_LAENGE        6
// ******************  alles nur für den JSON OUTPUT  ********************
#define JSON_OUTPUT                             // muss nur definiert sein. Sendet die Daten als JSON-String


// allgemeine Daten
float Feuchte_innen                =  0,           // Innen-Luftfeuchtigkeit, voerher H1
      Temperatur_innen             =  0,           // Innen-Tmperatur, vorher T1
      Feuchte_aussen               =  0,           // Außen-Luftfeuchtigkeit, vorher H2
      Temperatur_aussen            =  0,           // Außen-Temperatur, vorher T2
      Taupunkt_innen               =  0,           // Innen-Taupunkt
      Taupunkt_aussen              =  0,           // Außen-Taupunkt
      Feuchte_innen_alt            =  0,           // Innen-Luftfeuchtigkeit ALT
      Temperatur_innen_alt         =  0,           // Innen-Temperatur ALT
      Feuchte_aussen_alt           =  0,           // Außen-Luftfeuchtigkeit ALT
      Temperatur_aussen_alt        =  0,           // Außen-Temperatur ALT
      Taupunkt_innen_alt           =  0,           // Innen-Taupunkt ALT
      Taupunkt_aussen_alt          =  0,           // Außen-Taupunkt ALT
      DeltaTP                      =  0,           // Differenz der Taupunkte
      DeltaTP_alt                  =  0;           // Differenz der Taupunkte ALT

// beeinflusst das Schaltverhalten und Intervalle
float schalt_min                   =  SCHALT_MIN,  // minimale Differenz der Taupunkte für Aktivieren der Lüftung
      hysterese                    =  HYSTERESE,
      korrektur_temp_innen         =  KORREKTUR_TEMP_INNEN,
      korrektur_temp_aussen        =  KORREKTUR_TEMP_AUSSEN,
      korrektur_Feuchte_innen      =  KORREKTUR_FEUCHTE_INNEN,
      korrektur_Feuchte_aussen     =  KORREKTUR_FEUCHTE_AUSSEN,
      temp_innen_min               =  TEMP_INNEN_MIN,
      temp_aussen_min              =  TEMP_AUSSEN_MIN;
      
byte  sensor_intervall_byte        =  SENSOR_INTERVALL,
      seiten_intervall_byte        =  SEITEN_INTERVALL;
     
/*    // Vorbereitung um in einer der nächsten Versionen das Flackern bei der Setup-Anzeige zu deaktivieren
      schalt_min_alt               =  -666.0,
      hysterese_alt                =  -666.0,
      korrektur_temp_innen_alt     =  -666.0,
      korrektur_temp_aussen_alt    =  -666.0,
      korrektur_Feuchte_innen_alt  =  -666.0,
      korrektur_Feuchte_aussen_alt =  -666.0,
      temp_innen_min_alt           =  -666.0,
      temp_aussen_min_alt          =  -666.0; */
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
void loop() {

   wdt_reset();  // Watchdog zurücksetzen

   // Sensoren nur alle x Sekunden lesen
   if (zeit_differenz(timer_sensors) > long(sensor_intervall_byte) * 1000) {
      lese_sensoren();
      pruefe_sensoren();
      reboot_bei_fehler();
      errechne_beide_taupunkte();
      timer_sensors=millis();
      serial_ausgabe_werte();
   }

   // alle paar Sekunden wird die Seite umgeschaltet
   if (zeit_differenz(seitentimer_start) > long(seiten_intervall_byte) * 1000) {
      seite_alt=seite;
      rel_alt = !rel;
      seite++;
      timer_minuten_alt = 0; // damit bei Wechsel auf Seite 2 auch der Wert aktualisiert wird
      seitentimer_start = millis();  // Interner Timer = Start
      #ifdef DEBUG
         if (seite > 2) seite = 2; // DEBUGGING only
      #else
         if (seite > 2) seite = 1;
      #endif
   }

   // alle paar MilliSekunden wird das Symbol umgeschaltet
   if (zeit_differenz(timer_symbol) > SYMBOL_INTERVALL) {
      symbol_zeiger++;
      if (symbol_zeiger > MAX_SYMBOLE - 1) symbol_zeiger = 0;
      timer_symbol = millis();  // Interner Timer = Start
   }

  
   if (seite_alt != seite) {
      display_ausgabe_maske();
      display_ausgabe_werte(FORCE);
      seite_alt=seite;
   } else {
      display_ausgabe_werte(false);
   }

   interrupt_delay_routine(100); // Zeit um das Display zu lesen

   // wenn man am Timer-Knopf dreht, möchte man nicht erst auf Wechsel der Seite warten
   if (timer_minuten != timer_minuten_alt) {
      seite = 2;
      seitentimer_start = millis();  // Interner Timer = Start      
   }

   relais_schalten();

   // bei Timer-Betrieb Rotations-Symbol anzeigen
   lcd.setCursor(19,2);
   if (rest_laufzeit_sekunden > 0) lcd.write(char(symbol_zeiger)); else lcd.write(' ');

}


// Display-Test um beispielsweise Zeichen zu finden, die nicht ASCII Norm sind
// z.B. Grad-Zeichen, Umlaute usw.
void display_test() {
   lcd.clear();
   lcd.setCursor(0,0); for (int i=33; i<53; i++)   lcd.write(char(i)); 
   lcd.setCursor(0,1); for (int i=53; i<73; i++)   lcd.write(char(i));
   lcd.setCursor(0,2); for (int i=73; i<93; i++)   lcd.write(char(i));   
   lcd.setCursor(0,3); for (int i=93; i<113; i++)  lcd.write(char(i));
   while (!knopf_gedrueckt()) delay (100);
   delay(400);
   lcd.setCursor(0,0); for (int i=113; i<133; i++) lcd.write(char(i)); 
   lcd.setCursor(0,1); for (int i=133; i<153; i++) lcd.write(char(i));
   lcd.setCursor(0,2); for (int i=153; i<173; i++) lcd.write(char(i));   
   lcd.setCursor(0,3); for (int i=173; i<193; i++) lcd.write(char(i));
   while (!knopf_gedrueckt()) delay (100);
   delay(400);
   lcd.setCursor(0,0); for (int i=193; i<213; i++) lcd.write(char(i)); 
   lcd.setCursor(0,1); for (int i=213; i<233; i++) lcd.write(char(i));
   lcd.setCursor(0,2); for (int i=233; i<253; i++) lcd.write(char(i));   
   lcd.setCursor(0,3); for (int i=173; i<193; i++) lcd.write(char(127));
   while (!knopf_gedrueckt()) delay (100);
   delay(400);
   lcd.clear();  
}


void anzeige_programm_version() {
   lcd.clear();
   lcd.setCursor(0,0);
   lcd.print(F(TXT_CONST_DEWPOINT_VENT));
   lcd.setCursor(0,1);
   lcd.print(F(TXT_CONST_UNDERLINE_PRG));
   lcd.setCursor(3,2);
   lcd.print(F("Version: "));
   lcd.print(F(PRG_VERSION));
   lcd.setCursor(5,3);
   lcd.print(F(__DATE__));
   #ifndef DEBUG
      delay(2500);
   #endif
}


void anzeige_eeprom_status() {
   lcd.clear();
   lcd.setCursor(0,0);
   lcd.print(F("INFO:"));
   lcd.setCursor(0,1);
   lcd.print(F(TXT_CONST_EEPROM_SETTINGS));
   lcd.setCursor(0,2);

   if (EEPROM.read(EEPROM_BANK * EEPROM_BANKGROESSE) != EEPROM_ID_WERT) {
      lcd.print(F(TXT_CONST_SETTINGS_N_FOUND));
      lcd.setCursor(0,3);
      lcd.print(F(TXT_CONST_LOAD_DEFAULTS));
   } else {
      // Offset, der vor dem Speichern addiert wurde, wird nun abgezogen, halbiert wegen Reverse-Rechnung
      // Da die EEPROM-Zellen nur jeweils ein Byte speichern, wird da immer wieder umgerechnet.
      lcd.print(F(TXT_CONST_LOADING_SETTINGS));
      schalt_min               = float(EEPROM.read( 1 + EEPROM_BANK * EEPROM_BANKGROESSE)) / 2.0;
      hysterese                = float(EEPROM.read( 2 + EEPROM_BANK * EEPROM_BANKGROESSE)) / 2.0;
      korrektur_temp_innen     = float(EEPROM.read( 3 + EEPROM_BANK * EEPROM_BANKGROESSE)) / 2.0 - 10.0;
      korrektur_temp_aussen    = float(EEPROM.read( 4 + EEPROM_BANK * EEPROM_BANKGROESSE)) / 2.0 - 10.0;
      korrektur_Feuchte_innen  = float(EEPROM.read( 5 + EEPROM_BANK * EEPROM_BANKGROESSE)) / 2.0 - 15.0;
      korrektur_Feuchte_aussen = float(EEPROM.read( 6 + EEPROM_BANK * EEPROM_BANKGROESSE)) / 2.0 - 15.0;
      temp_innen_min           = float(EEPROM.read( 7 + EEPROM_BANK * EEPROM_BANKGROESSE)) / 2.0 - 15.0;
      temp_aussen_min          = float(EEPROM.read( 8 + EEPROM_BANK * EEPROM_BANKGROESSE)) / 2.0 - 15.0;
      seiten_intervall_byte    = float(EEPROM.read( 9 + EEPROM_BANK * EEPROM_BANKGROESSE)) / 2.0 - 15.0;
      sensor_intervall_byte    = float(EEPROM.read(10 + EEPROM_BANK * EEPROM_BANKGROESSE)) / 2.0 - 15.0;
      lcd.setCursor(0,3);
      lcd.print(F("OK."));
   }
   if (knopf_gedrueckt()) {
      delay(750);
   } else {
      delay(3000);
   }
}


// Setup-Routine, Anschauen und Werte setzen
// CAVE! Routine muss vor Aktivierung des Watchdog aufgerufen werden.
void werte_anzeige_und_einstellungen() {
   if (knopf_gedrueckt()) {
      lcd.clear();
      lcd.setCursor(0,0);
      // diese 3 Zeilen sind für Passwort-Eingabe vorgesehen
      //lcd.print(F(TXT_CONST_PASSWORD));
      //while (knopf_gedrueckt()) delay(50);
      //eingabe_passwort(10,0);
      
      setup_verlassen = false;
      menue_eintrag_alt = 255;
      lcd.clear();
      lcd.setCursor(0,0);
      lcd.print(F(TXT_CONST_MENUE));
      lcd.setCursor(0,1);
      lcd.print(F(TXT_CONST_UNDERLINE_MENUE));
      while (knopf_gedrueckt()) delay(50);

      while (!setup_verlassen) {
         menue_eintrag = map(analogRead(POTI_PIN),0,1023,0,11);
         if (menue_eintrag != menue_eintrag_alt) {
            menue_eintrag_alt = menue_eintrag;
            lcd.setCursor(0,2);
            lcd.print(F("                    "));
            lcd.setCursor(0,3);
            lcd.print(F("                    "));
            anzeige_eintrag();
         }
         delay(50);
         if (knopf_gedrueckt()) {
            while (knopf_gedrueckt()) delay(50);
            waehle_aktion();
            menue_eintrag_alt = 255; // damit das Menü neu ausgegeben wird
         }
      }
      delay(250);
      while (knopf_gedrueckt()) delay(50);
      lcd.clear();
      lcd.setCursor(0,0);
      lcd.print(F(TXT_CONST_SAVE_VALUES1));
      lcd.setCursor(0,1);
      lcd.print(F(TXT_CONST_SAVE_VALUES2));
      if ( eingabe_ja_nein(11,1) ) {
         lcd.setCursor(0,2);
         lcd.print(F(TXT_CONST_SAVE_TO_EEPROM));
         // Speicherroutine
         // hier wird das Setup in das EEPROM geschrieben

         #ifdef WRITE_EEPROM
            EEPROM.update( 0 + EEPROM_BANK * EEPROM_BANKGROESSE, EEPROM_ID_WERT);
            EEPROM.update( 1 + EEPROM_BANK * EEPROM_BANKGROESSE, byte(schalt_min * 2.0));
            EEPROM.update( 2 + EEPROM_BANK * EEPROM_BANKGROESSE, byte(hysterese  * 2.0));
            EEPROM.update( 3 + EEPROM_BANK * EEPROM_BANKGROESSE, byte(korrektur_temp_innen     * 2.0) + 20);
            EEPROM.update( 4 + EEPROM_BANK * EEPROM_BANKGROESSE, byte(korrektur_temp_aussen    * 2.0) + 20);
            EEPROM.update( 5 + EEPROM_BANK * EEPROM_BANKGROESSE, byte(korrektur_Feuchte_innen  * 2.0) + 30);
            EEPROM.update( 6 + EEPROM_BANK * EEPROM_BANKGROESSE, byte(korrektur_Feuchte_aussen * 2.0) + 30);
            EEPROM.update( 7 + EEPROM_BANK * EEPROM_BANKGROESSE, byte(temp_innen_min           * 2.0) + 30);
            EEPROM.update( 8 + EEPROM_BANK * EEPROM_BANKGROESSE, byte(temp_aussen_min          * 2.0) + 30);
            EEPROM.update( 9 + EEPROM_BANK * EEPROM_BANKGROESSE, byte(seiten_intervall_byte    * 2.0) + 30);
            EEPROM.update(10 + EEPROM_BANK * EEPROM_BANKGROESSE, byte(sensor_intervall_byte    * 2.0) + 30);
            lcd.print(F(TXT_CONST_CONFIG_SAVED));
         #endif
         delay(2000);
      }
   }
}


// Ja-Nein Abfrage
bool eingabe_ja_nein(byte xpos, byte ypos) {
      lcd.setCursor(xpos,ypos);
      ja_nein_poti_alt = 255;
      while(!knopf_gedrueckt()) {
         ja_nein_poti = map(analogRead(POTI_PIN),0,1023,0,10);
         if (ja_nein_poti != ja_nein_poti_alt) {
            ja_nein_poti_alt = ja_nein_poti;
            lcd.setCursor(xpos,ypos);
            if ((ja_nein_poti % 2) == 1) {
               lcd.print(F(TXT_CONST_ANSWER_YES));
            } else {
               lcd.print(F(TXT_CONST_ANSWER_NO));
            }
         }
         delay(50);
      }
      return ((ja_nein_poti % 2) == 1);
}
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

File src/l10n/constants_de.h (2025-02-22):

// Text-Konstanten für Lokalisierung: Deutsch

#define TXT_CONST_SENSOR_NAME_1        "Innen"
#define TXT_CONST_SENSOR_NAME_2        "Aussen"
#define TXT_CONST_TEMP_UNIT            "C"
#define TXT_CONST_TEST_SENSORS         "Teste Sensoren..."
#define TXT_CONST_EEPROM_SIZE          "EEPROM Größe: "
#define TXT_CONST_DEWPOINT_VENT        "  Taupunkt L\365ftung"
#define TXT_CONST_UNDERLINE_PRG        "===================="
#define TXT_CONST_EEPROM_SETTINGS      "EEPROM Einstellungen"
#define TXT_CONST_SETTINGS_N_FOUND     "nicht gefunden. ==>"
#define TXT_CONST_LOAD_DEFAULTS        "Standard-Werte."
#define TXT_CONST_LOADING_SETTINGS     "werden geladen."
#define TXT_CONST_OK                   "OK."
#define TXT_CONST_PASSWORD             "Passwort:"
#define TXT_CONST_MENUE                "Menue"
#define TXT_CONST_UNDERLINE_MENUE      "====="
#define TXT_CONST_SAVE_VALUES1         "Werte in EEPROM"
#define TXT_CONST_SAVE_VALUES2         "speichern?"
#define TXT_CONST_SAVE_TO_EEPROM       "Werte speichern...."
#define TXT_CONST_CONFIG_SAVED         "EEPROM geschrieben."
#define TXT_CONST_ANSWER_YES           "Ja  "
#define TXT_CONST_ANSWER_NO            "Nein"
#define TXT_CONST_THRESHOLD            "Schaltschwelle"
#define TXT_CONST_HYSTERESIS           "Hysterese"
#define TXT_CONST_CORR_TEMP_INSIDE     "Korrektur Temp Innen"
#define TXT_CONST_CORR_TEMP_OUTSIDE    "Korrektur Temp Au\342en"   //ß
#define TXT_CONST_CORR_HUMID_INSIDE    "Korr. Feuchte Innen"
#define TXT_CONST_CORR_HUMID_OUTSIDE   "Korr. Feuchte Au\342en"    // ß
#define TXT_CONST_MIN_TEMP_INSIDE      "Min. Innentemperatur"
#define TXT_CONST_MIN_TEMP_OUTSIDE     "Min. Au\342entemperatur"   // ß
#define TXT_CONST_PAGE_REFRESH         "Seiten-Intervall"
#define TXT_CONST_SENSOR_REFRESH       "Sensor-Intervall"
#define TXT_CONST_SECONDS              " Sekunden"
#define TXT_CONST_MINUTES              " Minuten"
#define TXT_CONST_HOURS                " Stunden"
#define TXT_CONST_DAYS                 " Tage"
#define TXT_CONST_SENSOR_INSIDE        "Sensor Innen: "
#define TXT_CONST_SENSOR_OUTSIDE       "Sensor Au\342en: "
#define TXT_CONST_ERR_SENSOR_INSIDE    "Fehler beim Auslesen des Innen-Sensors!"
#define TXT_CONST_ERR_SENSOR_OUTSIDE   "Fehler beim Auslesen des Außen-Sensors!"
#define TXT_CONST_ERROR                "Fehler"
#define TXT_CONST_CPU_RESTART          "CPU Neustart....."
#define TXT_CONST_SERIAL_HUMIDITY      "Luftfeuchtigkeit: "
#define TXT_CONST_SERIAL_TEMP          "%  Temperatur: "
#define TXT_CONST_SERIAL_DEWPOINT      "  Taupunkt: "
#define TXT_CONST_SERIAL_SENSOR_OUT    "Sensor-Außen: "
#define TXT_CONST_MASK_SENSOR_IN       "SI:                 "
#define TXT_CONST_MASK_SENSOR_OUT      "SA:                 "
#define TXT_CONST_MASK_DEWPT_IN        "TaupunktI:         "
#define TXT_CONST_MASK_DEWPT_OUT       "TaupunktA:         "
#define TXT_CONST_MASK_AIRING          "L\365ftung:"
#define TXT_CONST_MASK_DELTA_DPT       "Delta TP:"
#define TXT_CONST_MASK_TIMER           "Timer:"
#define TXT_CONST_MODE_ERROR           "Fehler: Betriebsart"
#define TXT_CONST_MODE_COMBI1          "Kombi1"
#define TXT_CONST_MODE_COMBI2          "Kombi2"
#define TXT_CONST_MODE_TIMER           " Timer"
#define TXT_CONST_MODE_AUTO            "  Auto"
#define TXT_CONST_ON                   "EIN"
#define TXT_CONST_OFF                  "---"
//                                      12345678901234567890

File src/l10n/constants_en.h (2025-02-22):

// Text-Constants for localization: English

#define TXT_CONST_SENSOR_NAME_1        "Inside"
#define TXT_CONST_SENSOR_NAME_2        "Outside"
#define TXT_CONST_TEMP_UNIT            "C"
#define TXT_CONST_TEST_SENSORS         "checking sensors..."
#define TXT_CONST_EEPROM_SIZE          "EEPROM size: "
#define TXT_CONST_DEWPOINT_VENT        "Dewpoint Ventilation"
#define TXT_CONST_UNDERLINE_PRG        "===================="
#define TXT_CONST_EEPROM_SETTINGS      "EEPROM settings"
#define TXT_CONST_SETTINGS_N_FOUND     "not found ==>"
#define TXT_CONST_LOAD_DEFAULTS        "loading defaults"
#define TXT_CONST_LOADING_SETTINGS     "loading..."
#define TXT_CONST_OK                   "OK."
#define TXT_CONST_PASSWORD             "password:"
#define TXT_CONST_MENUE                "menue"
#define TXT_CONST_UNDERLINE_MENUE      "====="
#define TXT_CONST_SAVE_VALUES1         "save config"
#define TXT_CONST_SAVE_VALUES2         "to EEPROM?"
#define TXT_CONST_SAVE_TO_EEPROM       "saving config...."
#define TXT_CONST_CONFIG_SAVED         "configuration saved."
#define TXT_CONST_ANSWER_YES           "Yes "
#define TXT_CONST_ANSWER_NO            "No  "
#define TXT_CONST_THRESHOLD            "threshold"
#define TXT_CONST_HYSTERESIS           "hysteresis"
#define TXT_CONST_CORR_TEMP_INSIDE     "correct temp inside"
#define TXT_CONST_CORR_TEMP_OUTSIDE    "correct temp outside"
#define TXT_CONST_CORR_HUMID_INSIDE    "correct humid inside"
#define TXT_CONST_CORR_HUMID_OUTSIDE   "correct humid outs."
#define TXT_CONST_MIN_TEMP_INSIDE      "min temp inside"
#define TXT_CONST_MIN_TEMP_OUTSIDE     "min temp outside"
#define TXT_CONST_PAGE_REFRESH         "page refresh"
#define TXT_CONST_SENSOR_REFRESH       "sensor refresh"
#define TXT_CONST_SECONDS              " seconds"
#define TXT_CONST_MINUTES              " minutes"
#define TXT_CONST_HOURS                " hours"
#define TXT_CONST_DAYS                 " days"
#define TXT_CONST_SENSOR_INSIDE        "sensor inside: "
#define TXT_CONST_SENSOR_OUTSIDE       "sensor outside: "
#define TXT_CONST_ERR_SENSOR_INSIDE    "error reading inside sensor!"
#define TXT_CONST_ERR_SENSOR_OUTSIDE   "error reading outside sensor!"
#define TXT_CONST_ERROR                "ERROR"
#define TXT_CONST_CPU_RESTART          "CPU restarting....."
#define TXT_CONST_SERIAL_HUMIDITY      "humidity: "
#define TXT_CONST_SERIAL_TEMP          "%  temperature: "
#define TXT_CONST_SERIAL_DEWPOINT      "  dewpoint: "
#define TXT_CONST_SERIAL_SENSOR_OUT    "sensor outside: "
#define TXT_CONST_MASK_SENSOR_IN       "SI:                 "
#define TXT_CONST_MASK_SENSOR_OUT      "SO:                 "
#define TXT_CONST_MASK_DEWPT_IN        "DewpointI:         "
#define TXT_CONST_MASK_DEWPT_OUT       "DewpointO:         "
#define TXT_CONST_MASK_AIRING          "Airing: "
#define TXT_CONST_MASK_DELTA_DPT       "DeltaDEW:"
#define TXT_CONST_MASK_TIMER           "Timer:"
#define TXT_CONST_MODE_ERROR           "Error: MODE"
#define TXT_CONST_MODE_COMBI1          "combi1"
#define TXT_CONST_MODE_COMBI2          "combi2"
#define TXT_CONST_MODE_TIMER           " timer"
#define TXT_CONST_MODE_AUTO            "  auto"
#define TXT_CONST_ON                   "O N"
#define TXT_CONST_OFF                  "- -"
//                                      12345678901234567890
